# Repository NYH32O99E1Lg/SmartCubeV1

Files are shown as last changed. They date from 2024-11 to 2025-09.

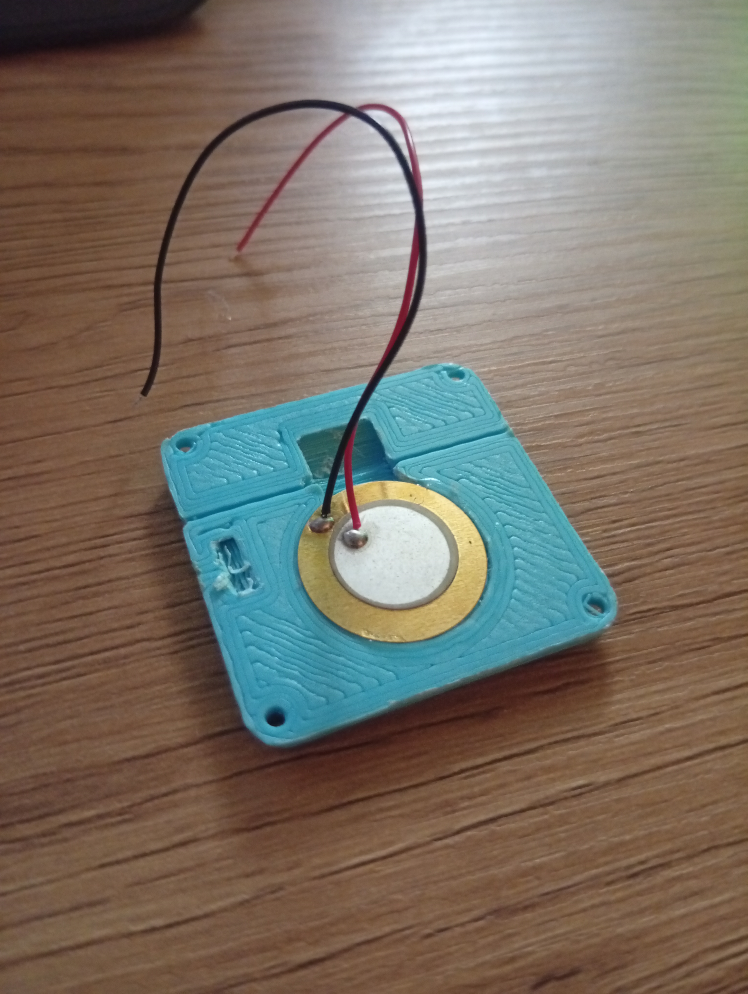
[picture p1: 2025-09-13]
hardware/pictures/build9.jpg

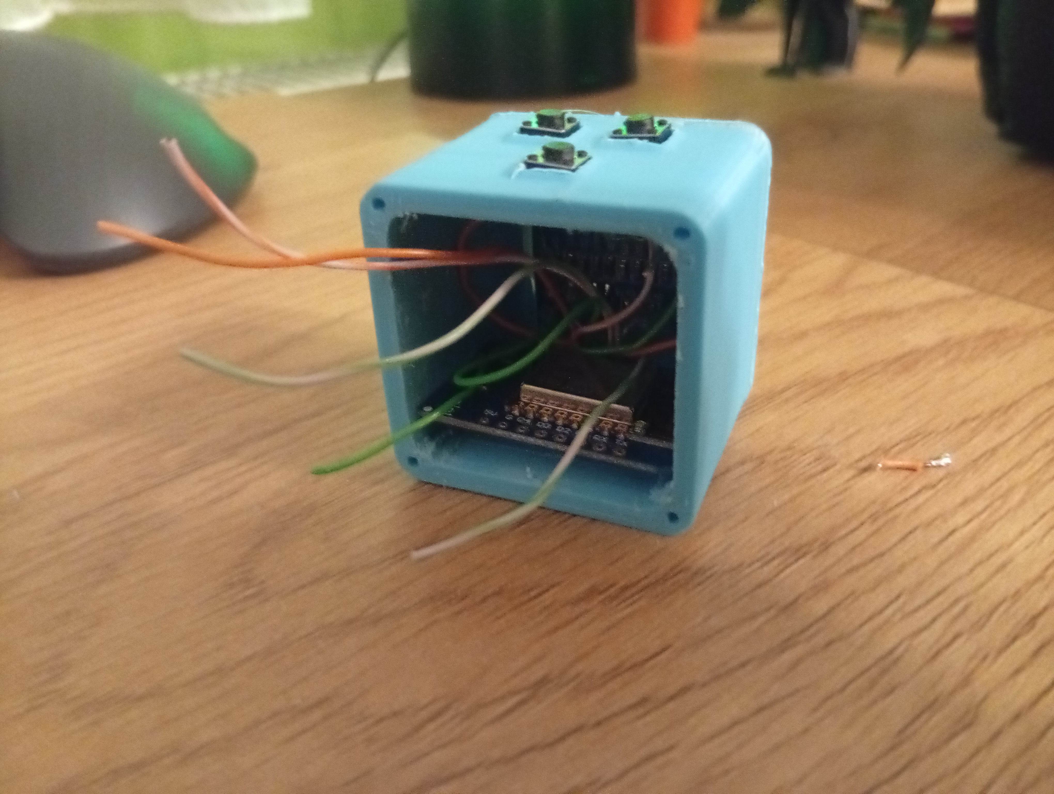
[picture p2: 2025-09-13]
hardware/pictures/build8.jpg

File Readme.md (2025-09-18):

# SmartCube

is a compact, customizable desk companion powered by an ESP8266 microcontroller.
Built entirely from cheap, easy-to-find parts, it can be programmed for a variety of tasks:
show notifications, display the weather, monitor sensors, act as a clock, host a simple web page, serve as a WiFi extender, run small background tasks, or even be a virtual pet 

Whatever you feel like experimenting with!

SmartCube

---

## Info    
- **This is a hobby project I work on and develop for when I have literally nothing else to do, do not expect regular updates. You are free to clone this and do whatever you like with it**
- **Code**: I have a few projects developed for the Cube. You can see the list [here on my Gitea](https://git.kopic.hr/tomislav?tab=repositories&q=cube&sort=recentupdate) 
- **V2**: There is also a more [powerful version](https://git.kopic.hr/tomislav/SmartCubeV2), it's pretty much the same but with extra features and is using ESP32, I only made one of them and I don't like it yet, it needs work. 
- **Case**: 3D-printable design included in `/hardware` directory  
- **Schematics**: and assembly instructions are also in the `/hardware` directory

---

### Table of Contents

1. [Bill of Materials](#bill-of-materials)
2. [3D-Printing the Case](#3d-printing-the-case)
3. [Assembly Instructions](#assembly-instructions)
   * [Body](#body)
   * [Buttons](#buttons)
   * [OLED Display](#oled-display)
   * [Buzzer](#buzzer)
   * [Battery Setup](#battery-setup)
4. [Schematics](#schematics)
5. [GPIO Pin Reference Table](#gpio-pin-reference-table)
6. [Demo Code Explanation](#demo-code-explanation)
   * [Getting Started](#getting-started)
   * [Uploading with PlatformIO](#uploading-with-platformio)
   * [Project Structure](#project-structure)
   * [What the Code Does](#what-the-code-does)
   * [Key Features](#key-features)
     * [WiFi Management](#wifi-management)
     * [Button Handling](#button-handling)
       * [Default Button Actions](#default-button-actions)
7. [Tips and tricks](#tips-and-tricks)

---

## Bill of Materials  

| **Component** | **Quantity** | **Description** | **Notes** |  
|---|---|---|---|
| Enclosure | 1 | 3D-printed case | 3D printable STL files are in `hardware/case/` |
| ESP8266 D1 Mini | 1 | Microcontroller module | |
| SSD1306 OLED Display | 1 | 128x64 resolution, I2C interface | |
| 6x6 Push Buttons | 3 or 4 | Tactile push buttons | |
| Resistors (10kΩ) | 3 or 4 | Pull-down resistors for buttons | Generally any resistor between 1kΩ and 100kΩ will work |
| 20mm Piezo Buzzer | 1 | Caseless buzzer for audio | |
| Wires | Several | Thin wires for connections | I used wires from inside an old ethernet cable |  
| 2x6mm screw | 8 | Small screws for assembling the case | Does not have to be exactly 6mm long |  
| 2x2mm screw | 4 (Optional) | Small screws for the front | Mostly for cosmetic purposes |  
| 14250 Rechargeable Battery| 1 (Optional) | Lithium-ion battery | Make sure it's rechargeable; most 14250 aren't |  
| TP4056 Module | 1 (Optional) | Charging and protection circuit | USB connector not required |
| Resistors (220kΩ and 56kΩ)| 1 (Optional) | Voltage divider for measuring battery level  | You can also use 100kΩ and 47kΩ |
| Micro Slider Switch (SS-12D00) | 1 (Optional) | On/Off switch | Only needed if installing the battery |  

layout
---

### 3D-Printing the Case

The SmartCube case is fully 3D-printable. STL files are included this repository in the `/hardware/case/` directory:

| **File** | **Description** |
| --- | --- |
| `SmartCube_Body_3_button.stl` | Main cube body with slots for 3 buttons |
| `SmartCube_Body_4_button.stl` | Body variant for 4 buttons |
| `SmartCube_Front.stl` | Front panel for OLED display |
| `SmartCube_Front_No_Holes.stl` | Front panel variant without decorative screw holes |
| `SmartCube_Back_Speaker_Side_Hole.stl` | Back panel |
| `SmartCube_Back_Speaker_Power_Switch.stl` | Back panel variant with power switch slot |

* Use PLA or PETG
* 0.2 mm layer hight is more than enough, you can print finer if you want to.
* Supports may be required depending on your printer

## Assembly Instructions  
---
### Body

Push the ESP8266 microcontroller in the ledge on the bottom [the cube body](https://git.kopic.hr/tomislav/SmartCubeV1/raw/branch/main/hardware/case/SmartCube_Body_3_button.stl), it should 'click in' with the USB-C port facing the hole.

Body with 3 or 4 button slots is available in the `hardware/case/`

Step3

Step1

Step2

---

### Buttons

At this step, glue the buttons into the top slots and solder resistors to their outputs. You can connect the resistor outputs together, and don't forget to attach an extra wire to the button inputs, this will later be used to connect them to the 3.3V line.

Step4

Next, solder all of the button outputs to the microcontroller.

Pin numbers for the buttons (and other components) are defined in the [example config](https://git.kopic.hr/tomislav/SmartCubeV1/src/branch/main/src/example_config.h), and the schematic for the [D1 Mini is here](https://git.kopic.hr/tomislav/SmartCubeV1/raw/branch/main/hardware/schematics/esp8266.png).
You don't have to follow my exact pin definitions, but I've found this setup to be the easiest way to assemble and fit everything in. The 3-button variant is the standard. If you decide to go with 4 buttons, you'll need to define the extra pin yourself in the code.

* Button Left (PIN_BTN_L): (D6) GPIO12
* Button Middle (PIN_BTN_M): (D7) GPIO13
* Button Right (PIN_BTN_R): (D8) GPIO15

Finally, solder the GND wire to the resistor outputs and connect 3.3V to the button inputs.

Step5

---
### OLED Display

Screw in the 2x2mm screws and hot glue the SSD1306 to the [front part of the cube](https://git.kopic.hr/tomislav/SmartCubeV1/raw/branch/main/hardware/case/SmartCube_Front.stl) solder the 4 wires to the OLED display, make sure you have some extra length, 4-5cm should be more than enough

Step6

Step7

The OLED display must be connected via I2C on pins:
- **SDA**: D2 (GPIO4)  
- **SCL**: D1 (GPIO5)  
- **GND**: GND
- **VCC**: 3.3V pin or directly to the TP4056 output

Step8

---
### Buzzer

Glue in the buzzer to the [back part of the cube](https://git.kopic.hr/tomislav/SmartCubeV1/raw/branch/main/hardware/case/SmartCube_Back_Speaker_Side_Hole.stl) with superglue

As defined in the [example config](https://git.kopic.hr/tomislav/SmartCubeV1/src/branch/main/src/example_config.h) connect:
  - the positive wire of the buzzer to the 3.3V
  - the negative wire to PIN_BUZZER (D3) GPIO0

Step9
---

### Battery Setup

The battery is optional. Your SmartCube will work fine when powered via USB; however, adding one makes it portable (and much cuter).

A single 700 mAh 14250 battery lasts about 24 hours.
The TP4056 prevents the cell from being completely drained and should protect it from damage.

Although it's not shown in any of the pictures or schematics, both the case and the back cover are updated to include a slot for 8.5mm SPDT slider switch(SS-12D00), in case you actually want to have a power switch instead of letting it run until the battery drains.

* Solder the 14250 battery to the **TP4056 input pins**.
* Wire the **TP4056 output** to the **3.3V pin** on the D1 Mini to power the device.
* Connect the **5V output pin** from the D1 Mini to the **TP4056 input port** to allow charging through the USB data port on the ESP8266.
* *(Optional)* Add a **voltage divider** to monitor battery level on the ESP8266 **A0 pin**:
  * **R1 = 220kΩ** (between battery positive and A0)
  * **R2 = 56kΩ** (between A0 and GND)

    This scales the battery voltage safely down for measurement (~0-0.85V).

As mentioned in the [Bill of Materials](#bill-of-materials) you can also use 100kΩ and 47kΩ resistors, just be sure to edit [example config](https://git.kopic.hr/tomislav/SmartCubeV1/src/branch/main/src/example_config.h)

batt1

batt2

batt3

---
## Schematics

This is the basic drawing of the circuit without the battery

Basic

This is the complete circuit including the battery and a voltage divider

WithBattery

---

### GPIO Pin Reference Table

| **Component** | **GPIO Pin** | **PlatformIO / Code Macro** |
| --- | --- | --- |
| Left Button | D6 (GPIO12)  | `PIN_BTN_L` |
| Middle Button | D7 (GPIO13)  | `PIN_BTN_M` |
| Right Button | D8 (GPIO15)  | `PIN_BTN_R` |
| Buzzer | D3 (GPIO0) | `PIN_BUZZER` |
| OLED SDA | D2 (GPIO4) | `SDA` |
| OLED SCL | D1 (GPIO5) | `SCL` |
| Battery Voltage Divider | A0 | `A0` |

---

## Demo Code Explanation

This repository contains a basic "Hello, World!" project for the SmartCube.

### Getting Started:

1. Download and install **[VSCode](https://code.visualstudio.com/)** or **[VSCodium](https://vscodium.com/)**.
2. Install the **[PlatformIO IDE extension](https://platformio.org/platformio-ide)**.
3. Clone this repository and open the project folder in VSCode/VSCodium.
4. PlatformIO will automatically handle environment setup and dependencies when you open the project.

### Uploading with PlatformIO

Once you open this git repository in VSCode and install the PlatformIO extension.

You can click on the PlatformIO icon on the left sidebar

platformio1

In the PlatformIO panel, expand d1_mini_lite → General to reveal the available tasks.

Click Build to compile the firmware, and then click Upload to flash it to your SmartCube.

platformio2

### Project Structure:

All source code is located in the `src/` directory.
You should start by opening **`src/main.cpp`**, which contains the entry point and initialization logic.

### What the Code Does:

This demo handles basic system functionality, including:

* System initialization
* Button input handling
* OLED display output configuration
* WiFi management

### Key Features  

#### WiFi Management
   - The [cubeWifiManager](https://git.kopic.hr/tomislav/SmartCubeV1/src/branch/main/src/SmartCube/cubeWifiManager.h) class manages WiFi connectivity seamlessly.  
   - If no known WiFi network is available, it starts a configuration portal and creates an access point (AP), allowing users to connect the SmartCube to a network from another WiFi-enabled device.  
   - The OLED display shows the access point details, such as the AP name and IP address, making the setup process very easy.

#### Button Handling
   - Buttons are mapped to specific GPIO pins: `PIN_BTN_L` (Left), `PIN_BTN_M` (Middle), and `PIN_BTN_R` (Right).  
   - The [cubeButtonHandler](https://git.kopic.hr/tomislav/SmartCubeV1/src/branch/main/src/SmartCube/cubeButtons.h) function, executed in the [loop()](https://git.kopic.hr/tomislav/SmartCubeV1/src/commit/1cb51f502d92a91c6a83ce6364b434db31bfd864/src/main.cpp#L47), monitors and interprets button presses, differentiating between short and long presses.  

##### Default Button Actions  
- **Right Button**:  
  - *Long Press*: Turns the OLED display **on** (if previously off).  

- **Left + Middle Buttons (Simultaneous Long Press)**:  
  - Triggers an ESP8266 reboot, effectively restarting the device.  

This is meant to provide a minimal starting point for further development with the SmartCube.

---
## Tips and tricks  

- It's not as hard to make as it looks.
- Battery is the trickiest part to fit in, it's best to put in the case last.
- Test if everything works before completely closing the case shut. 
- Make sure all connections are secure and not short-circuited. 
- Hot glue is your friend, it will add extra protection from short-circuits and keep wires in place.
- Everything is pretty tightly packed in there and it can be quite a mess.

Packed

For questions or additional details, feel free to reach out! I would love to hear some feedback.
Good luck and have fun :)

Done

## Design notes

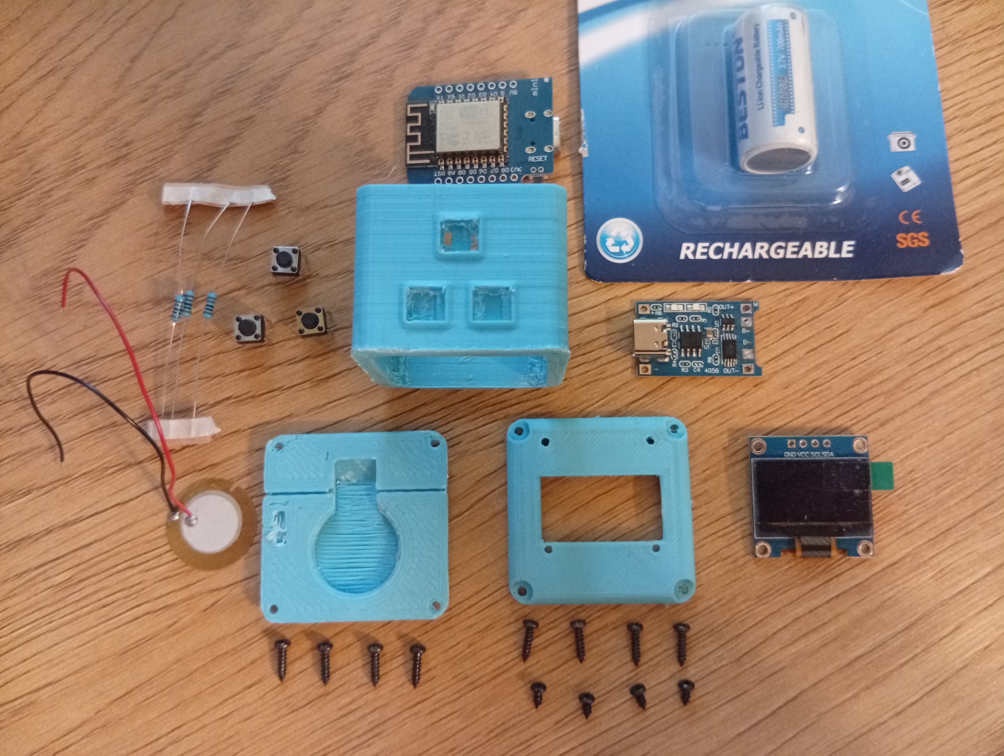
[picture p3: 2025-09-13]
hardware/pictures/layout.jpg

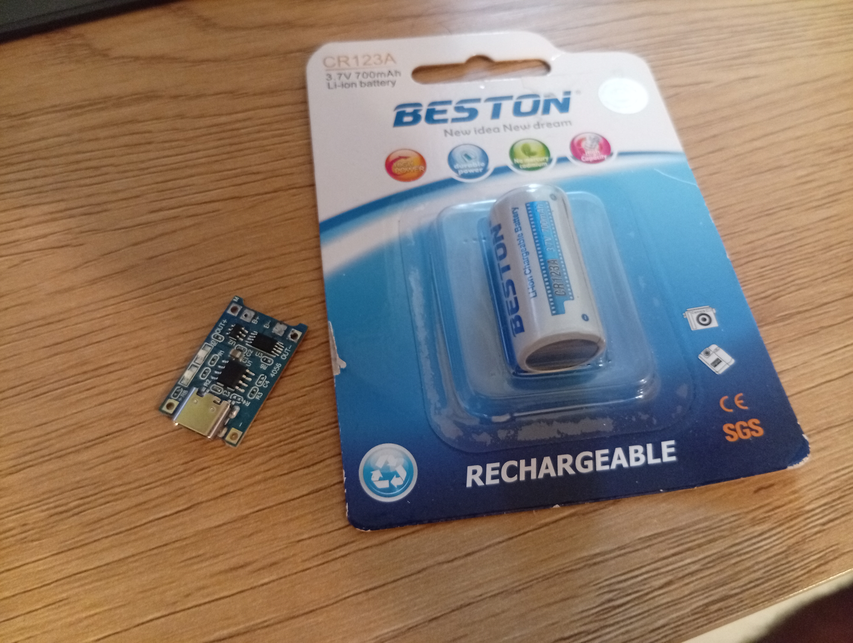
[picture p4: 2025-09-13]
hardware/pictures/batt2.jpg

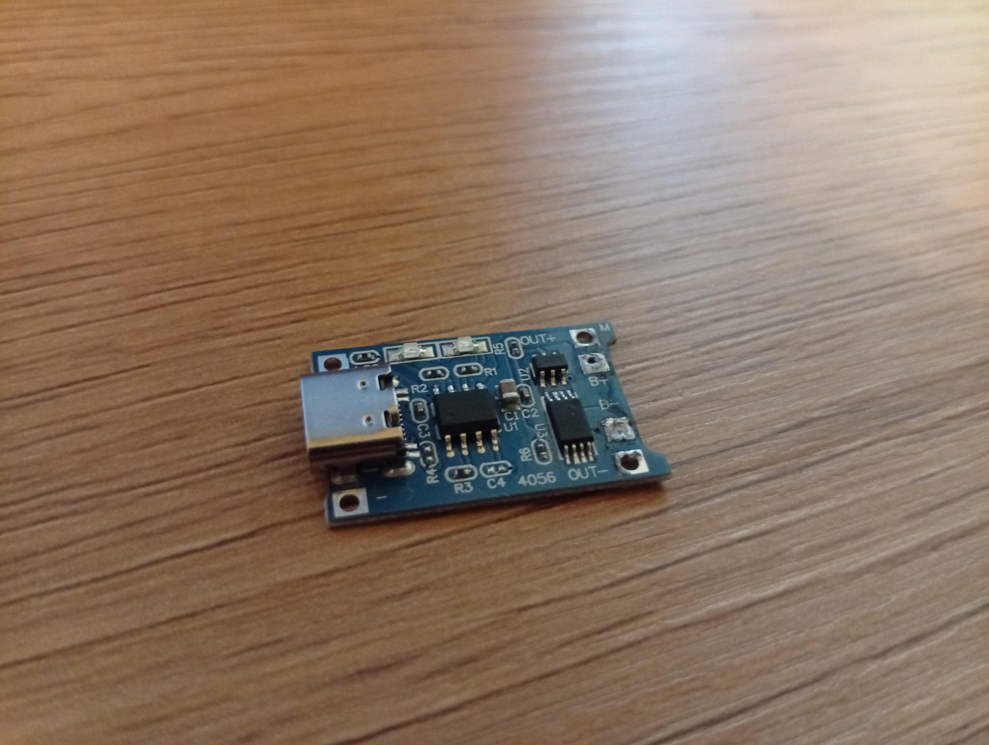
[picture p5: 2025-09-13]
hardware/pictures/batt1.jpg

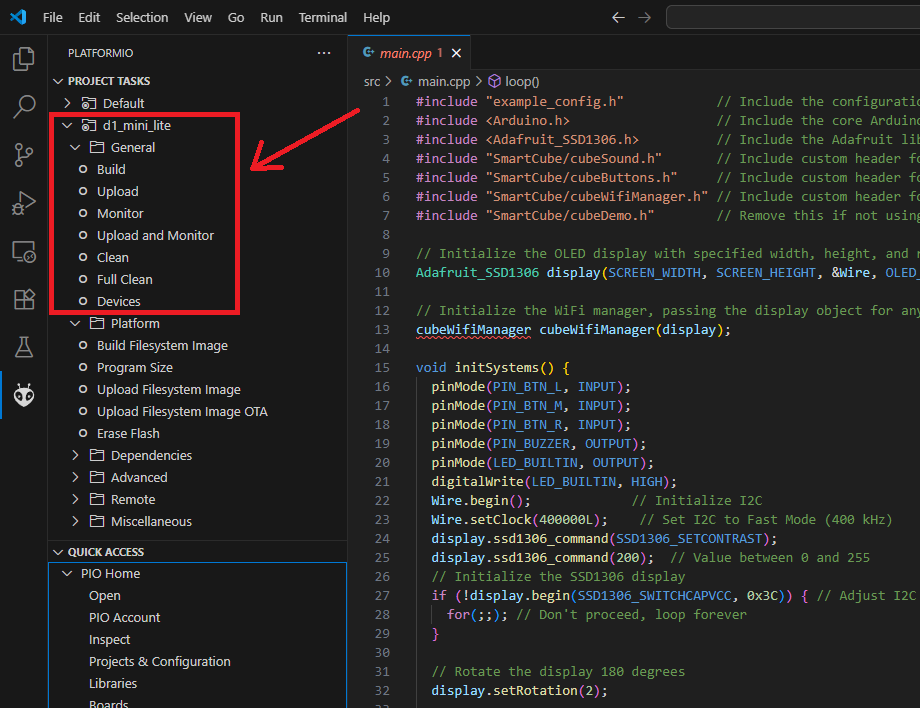
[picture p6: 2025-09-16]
hardware/pictures/platformio2.png

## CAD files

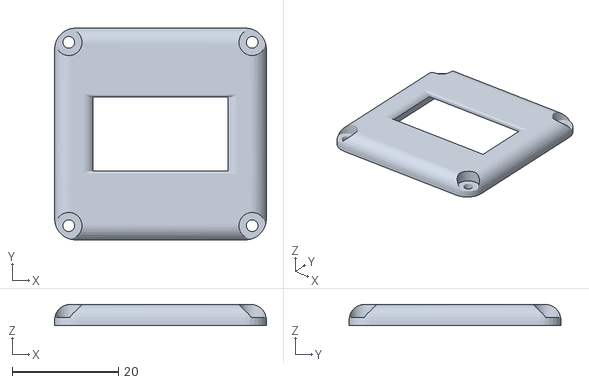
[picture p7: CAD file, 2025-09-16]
hardware/case/SmartCube_Front_No_Holes.stl
40.0 x 40.0 x 4.00

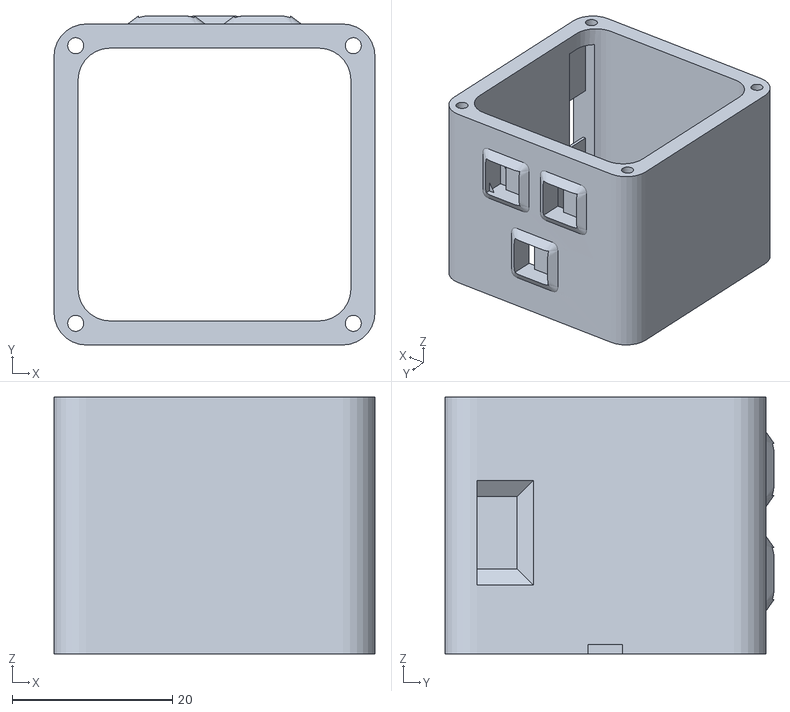
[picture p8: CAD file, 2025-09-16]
hardware/case/SmartCube_Body_3_button.stl
40.0 x 41.0 x 32.0

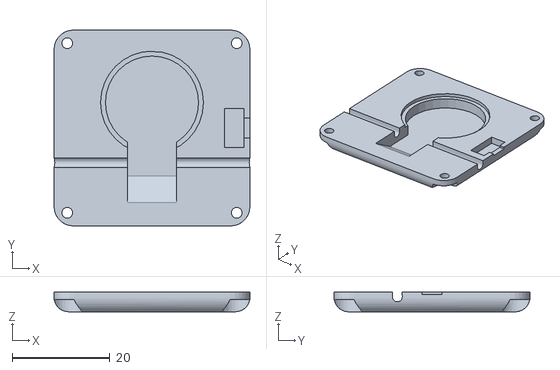
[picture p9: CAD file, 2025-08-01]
hardware/case/SmartCube_Back_Speaker_Power_Switch.stl
40.0 x 40.0 x 4.00

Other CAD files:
hardware/case/SmartCube_Body_4_button.stl
hardware/case/SmartCube_Back_Speaker_Side_Hole.stl
hardware/case/SmartCube_Front.stl

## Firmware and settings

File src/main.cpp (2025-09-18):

#include "example_config.h"              // Include the configuration header file
#include <Arduino.h>                     // Include the core Arduino library
#include <Adafruit_SSD1306.h>            // Include the Adafruit library for the SSD1306 OLED display
#include "SmartCube/cubeSound.h"         // Include custom header for sound functions
#include "SmartCube/cubeButtons.h"       // Include custom header for button handling functions
#include "SmartCube/cubeWifiManager.h"   // Include custom header for managing WiFi connections
#include "SmartCube/cubeBattery.h"       // Remove this if not using demo functions
#include "SmartCube/cubeDemo.h"          // Remove this if not using demo functions

// Initialize the OLED display with specified width, height, and reset pin
Adafruit_SSD1306 display(SCREEN_WIDTH, SCREEN_HEIGHT, &Wire, OLED_RESET);

// Initialize the WiFi manager, passing the display object for any display output
cubeWifiManager cubeWifiManager(display);

void initSystems() {
  pinMode(PIN_BTN_L, INPUT);
  pinMode(PIN_BTN_M, INPUT);
  pinMode(PIN_BTN_R, INPUT);
  pinMode(PIN_BUZZER, OUTPUT);
  pinMode(LED_BUILTIN, OUTPUT);
  digitalWrite(LED_BUILTIN, HIGH);
  Wire.begin();             // Initialize I2C
  Wire.setClock(400000L);    // Set I2C to Fast Mode (400 kHz)
  display.ssd1306_command(SSD1306_SETCONTRAST);
  display.ssd1306_command(200);  // Value between 0 and 255
  // Initialize the SSD1306 display
  if (!display.begin(SSD1306_SWITCHCAPVCC, 0x3C)) { // Adjust I2C address if needed
    for(;;); // Don't proceed, loop forever
  }

  // Rotate the display 180 degrees
  display.setRotation(2);

  // Clear the display buffer
  display.clearDisplay();
  display.setTextSize(1);      
  display.setTextColor(WHITE);
  display.setCursor(0, 0);
  display.display();
}

void setup() {
  initSystems();
  cubeWifiManager.start(); // Start the WiFi manager
}

void loop() {
  interactiveCubeDemo(); // Run the demo screen animation
  cubeButtonHandler();   // Continuously check and handle button actions
}

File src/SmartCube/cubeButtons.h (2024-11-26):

extern Adafruit_SSD1306 display;    // Reference to the OLED display object
bool is_display_off = false;        // State variable to track display on/off status

unsigned long buttonDebounceDelay = 50;       // Debounce delay in milliseconds
unsigned long buttonLongPressDelay = 2000;    // Long press threshold in milliseconds

void cubeButtonHandler() {
    unsigned long currentMillis = millis(); // Get the current time in milliseconds

    // Track the start times of button presses
    static unsigned long leftPressStart = 0;
    static unsigned long middlePressStart = 0;
    static unsigned long rightPressStart = 0;

    // Track if a beep has already been played for each button to avoid repeated beeping
    static bool leftBeeped = false;
    static bool middleBeeped = false;
    static bool rightBeeped = false;

    // Check if each button is currently pressed
    bool leftPressed = (digitalRead(PIN_BTN_L) == HIGH);
    bool middlePressed = (digitalRead(PIN_BTN_M) == HIGH);
    bool rightPressed = (digitalRead(PIN_BTN_R) == HIGH);

    // Short press detection for left button
    if (leftPressed) {
        // Check if the button is held beyond the debounce delay
        if ((currentMillis - leftPressStart > buttonDebounceDelay)) {
            if (!leftBeeped) { 
                beep(1000);  // Play beep for a short press
                leftBeeped = true; // Mark as beeped to avoid repeat beeps
                // Handle left short press action here
            }
        }
    } else {
        leftPressStart = currentMillis;  // Reset timer when button is released
        leftBeeped = false;              // Reset beep flag for next press
    }

    // Short press detection for middle button
    if (middlePressed) {
        if ((currentMillis - middlePressStart > buttonDebounceDelay)) {
            if (!middleBeeped) {
                beep(1000);  // Play beep for a short press
                middleBeeped = true; // Mark as beeped to avoid repeat beeps
                // Handle middle short press action here
            }
        }
    } else {
        middlePressStart = currentMillis;  // Reset timer when button is released
        middleBeeped = false;              // Reset beep flag for next press
    }

    // Short press detection for right button
    if (rightPressed) {
        if ((currentMillis - rightPressStart > buttonDebounceDelay)) {
            if (!rightBeeped) {
                beep(1000);  // Play beep for a short press
                rightBeeped = true; // Mark as beeped to avoid repeat beeps
                if (is_display_off) { 
                    display.ssd1306_command(SSD1306_DISPLAYON); // Turn on the display
                    is_display_off = false;    // Update display state
                    beep(1300);  // Additional beep to confirm display is on
                }
            }
        }
    } else {
        rightPressStart = currentMillis;  // Reset timer when button is released
        rightBeeped = false;              // Reset beep flag for next press
    }

    // Long press detection for left button
    if (leftPressed && (currentMillis - leftPressStart > buttonLongPressDelay)) {
        if (!leftBeeped) {
            beep(1000);  // Play beep for a long press
            leftBeeped = true; // Mark as beeped to avoid repeat beeps
            // Handle left long press action here
        }
    }

    // Long press detection for middle button
    if (middlePressed && (currentMillis - middlePressStart > buttonLongPressDelay)) {
        if (!middleBeeped) {
            beep(1000);  // Play beep for a long press
            middleBeeped = true; // Mark as beeped to avoid repeat beeps
            // Handle middle long press action here
        }
    }

    // Long press detection for right button (with display control)
    if (rightPressed && (currentMillis - rightPressStart > buttonLongPressDelay)) {
        if (!is_display_off) { // Turn off the display if it's on
            beep(1300); // Beep to indicate display turn-off
            display.ssd1306_command(SSD1306_DISPLAYOFF); // Turn off the display
            is_display_off = true;     // Update display state
            beep(1000);  // Additional beep to confirm display is off
        }
    }

    // Combined long press detection for left and middle buttons to restart device
    if (leftPressed && middlePressed && 
        (currentMillis - leftPressStart > buttonLongPressDelay) && (currentMillis - middlePressStart > buttonLongPressDelay)) {
            ESP.restart();  // Restart device if both buttons are held long enough
    }
}

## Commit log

2024-11-26 Fix up segmentation fault
    [cubeButtons.h, main.cpp]
2024-12-07 Add screws to the bill of materials
2025-08-01 Upload files to "hardware/case"
    [SmartCube_Body_4_button.stl]
2025-08-01 Upload files to "/"
    [SmartCube_Back_Speaker_Power_Switch.stl]
2025-09-15 Allow skipping WiFi setup
    [cubeDemo.h, main.cpp]
2025-09-16 Upload files to "hardware/schematics"
2025-09-16 Add new STL file, update 3 button case, add battery meter functions
    [SmartCube_Body_3_button.stl, SmartCube_Front_No_Holes.stl]
2025-09-18 fix pin
2025-09-18 Fix battery value
